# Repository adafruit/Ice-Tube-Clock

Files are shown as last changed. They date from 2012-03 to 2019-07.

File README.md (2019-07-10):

# Ice Tube Clock kit - v1.1

__Format is EagleCAD schematic and board layout__

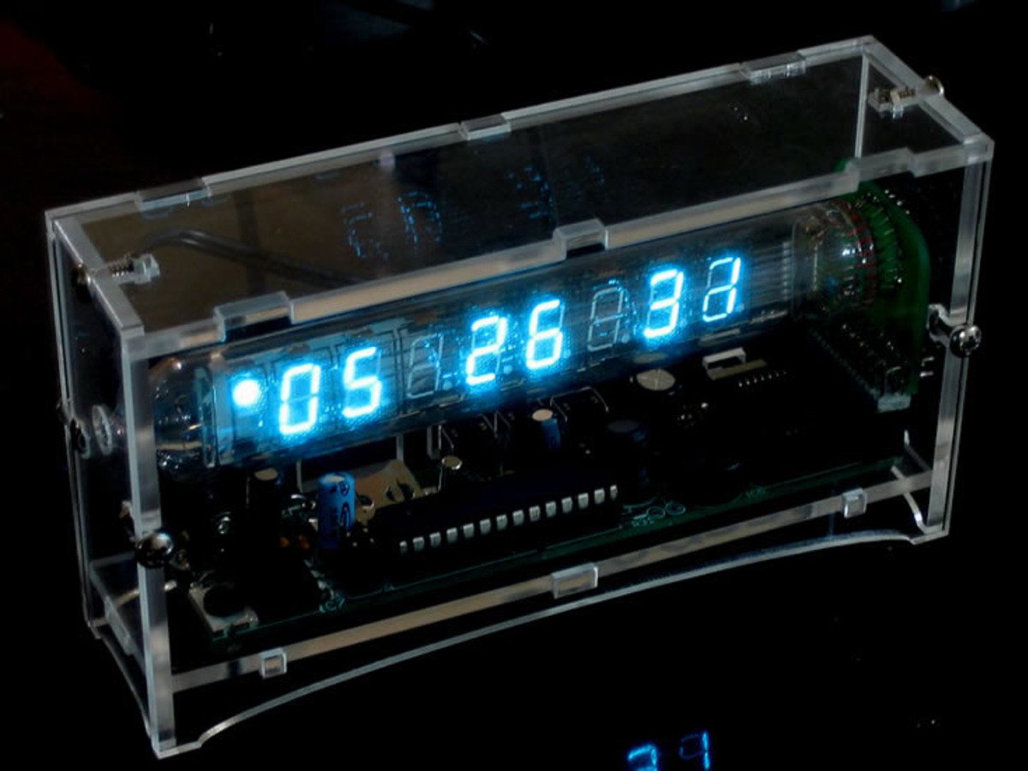
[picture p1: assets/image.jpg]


This is our first clock kit design, made with a retro Russian display tube!

* Cool glowing blue tube with 8 digits, PM dot and alarm on/off indicator
* Adjustable brightness
* Alarm with volume adjust
* Precision watch crystal keeps time with under 20ppm (0.0002%) error (< 2 seconds a day)
* Clear acrylic enclosure protects clock from you and you from clock
* Battery backup will let the clock keep the time for up to 2 weeks without power
* Selectable 12h or 24h display
* Displays day and date on button press
* 10 minute snooze
* Integrated boost converter so it can run off of standard DC wall adapters, works in any country regardless of mains power
* Great for desk or night table use, the clock measures 4.9" x 2.9" x 1.3" (12.5cm x 7.4cm x 3.3cm)
* Completely open source hardware and software, ready to be hacked and modded!

Complete kit comes with [a 110/220V 9VDC power supply](https://www.adafruit.com/products/63) (a $1 plug adapter from your local hardware store will allow it to be used worldwide), all components including PCB, vacuum fluorescent tube, backup battery and a clear acrylic enclosure. Assembly is required! This kit is made of through-hole components but is best built by someone with previous soldering experience as there are many parts and steps.

For assembly instructions, user manual, code, schematics, and more, please visit the [Ice Tube Clock webpage!](https://learn.adafruit.com/ice-tube-clock-kit/)

**Note: This kit is super popular, and the supply of tubes is harder to get. Thus the price is going to increase slowly but surely until the tubes are unavailable & the kit is discontinued. Thanks for your understanding!**

## License

Adafruit invests time and resources providing this open source design, 
please support Adafruit and open-source hardware by purchasing 
products from Adafruit!

Designed by Adafruit Industries.  
Creative Commons Attribution, Share-Alike license, check license.txt for more information
All text above must be included in any redistribution

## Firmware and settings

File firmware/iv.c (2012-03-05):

/***************************************************************************
 Ice Tube Clock with GPS firmware July 22, 2010
 (c) 2010 Limor Fried / Adafruit Industries
 GPS Capability added by Devlin Thyne

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
THE SOFTWARE IS PROVIDED "AS IS", WITHOUT WARRANTY OF ANY KIND, EXPRESS OR
IMPLIED, INCLUDING BUT NOT LIMITED TO THE WARRANTIES OF MERCHANTABILITY,
FITNESS FOR A PARTICULAR PURPOSE AND NONINFRINGEMENT. IN NO EVENT SHALL THE
AUTHORS OR COPYRIGHT HOLDERS BE LIABLE FOR ANY CLAIM, DAMAGES OR OTHER
LIABILITY, WHETHER IN AN ACTION OF CONTRACT, TORT OR OTHERWISE, ARISING FROM,
OUT OF OR IN CONNECTION WITH THE SOFTWARE OR THE USE OR OTHER DEALINGS IN
THE SOFTWARE.
****************************************************************************/

#include <avr/io.h>      
#include <string.h>
#include <avr/interrupt.h>   // Interrupts and timers
#include <util/delay.h>      // Blocking delay functions
#include <avr/pgmspace.h>    // So we can store the 'font table' in ROM
#include <avr/eeprom.h>      // Date/time/pref backup in permanent EEPROM
#include <avr/wdt.h>     // Watchdog timer to repair lockups
#include <stdlib.h>

#include "iv.h"
#include "util.h"
#include "fonttable.h"

uint8_t region = REGION_US;

// These variables store the current time.
volatile int8_t time_s, time_m, time_h;
// ... and current date
volatile int8_t date_m, date_d, date_y;

// how loud is the speaker supposed to be?
volatile uint8_t volume;

// whether the alarm is on, going off, and alarm time
volatile uint8_t alarm_on, alarming, alarm_h, alarm_m;

// what is being displayed on the screen? (eg time, date, menu...)
volatile uint8_t displaymode;

// are we in low power sleep mode?
volatile uint8_t sleepmode = 0;

volatile uint8_t timeunknown = 0;        // MEME
volatile uint8_t restored = 0;

// String buffer for processing GPS data:
char strBuffer[BUFFERSIZE];
uint8_t intBufferStatus = 0;

// Variables for the timezone offset if using GPS.
int8_t intTimeZoneHour = -6;  //Because Colorado is my time zone...
uint8_t intTimeZoneMin = 0;


// Our display buffer, which is updated to show the time/date/etc
// and is multiplexed onto the tube
uint8_t display[DISPLAYSIZE]; // stores segments, not values!
uint8_t currdigit = 0;        // which digit we are currently multiplexing

// This table allow us to index between what digit we want to light up
// and what the pin number is on the MAX6921 see the .h for values.
// Stored in ROM (PROGMEM) to save RAM
const uint8_t digittable[] PROGMEM = {
  DIG_9, DIG_8, DIG_7, DIG_6, DIG_5, DIG_4, DIG_3, DIG_2, DIG_1
};
PGM_P digittable_p PROGMEM = digittable;

// This table allow us to index between what segment we want to light up
// and what the pin number is on the MAX6921 see the .h for values.
// Stored in ROM (PROGMEM) to save RAM
const uint8_t segmenttable[] PROGMEM = {
  SEG_H, SEG_G,  SEG_F,  SEG_E,  SEG_D,  SEG_C,  SEG_B,  SEG_A 
};
PGM_P segmenttable_p PROGMEM = segmenttable;

// muxdiv and MUX_DIVIDER divides down a high speed interrupt (31.25KHz)
// down so that we can refresh at about 100Hz (31.25KHz / 300)
// We refresh the entire display at 100Hz so each digit is updated
// 100Hz/DISPLAYSIZE
uint16_t muxdiv = 0;
#define MUX_DIVIDER (300 / DISPLAYSIZE)

// Likewise divides 100Hz down to 1Hz for the alarm beeping
uint16_t alarmdiv = 0;
#define ALARM_DIVIDER 100

// How long we have been snoozing
uint16_t snoozetimer = 0;

// We have a non-blocking delay function, milliseconds is updated by
// an interrupt
volatile uint16_t milliseconds = 0;
void delayms(uint16_t ms) {
  sei();

  milliseconds = 0;
  while (milliseconds < ms);
}

// When the alarm is going off, pressing a button turns on snooze mode
// this sets the snoozetimer off in MAXSNOOZE seconds - which turns on
// the alarm again
void setsnooze(void) {
  //snoozetimer = eeprom_read_byte((uint8_t *)EE_SNOOZE);
  //snoozetimer *= 60; // convert minutes to seconds
  snoozetimer = MAXSNOOZE;
  DEBUGP("snooze");
  display_str("snoozing");
  displaymode = SHOW_SNOOZE;
  delayms(1000);
  displaymode = SHOW_TIME;
}

// we reset the watchdog timer 
void kickthedog(void) {
  
  wdt_reset();

}

// called @ (F_CPU/256) = ~30khz (31.25 khz)
SIGNAL (SIG_OVERFLOW0) {
  // allow other interrupts to go off while we're doing display updates
  sei();

  // kick the dog
  kickthedog();

  // divide down to 100Hz * digits
  muxdiv++;
  if (muxdiv < MUX_DIVIDER)
    return;
  muxdiv = 0;
  // now at 100Hz * digits

  // ok its not really 1ms but its like within 10% :)
  milliseconds++;

  // Cycle through each digit in the display
  if (currdigit >= DISPLAYSIZE)
    currdigit = 0;

  // Set the current display's segments
  setdisplay(currdigit, display[currdigit]);
  // and go to the next
  currdigit++;

  // check if we should have the alarm on
  if (alarming && !snoozetimer) {
    alarmdiv++;
    if (alarmdiv > ALARM_DIVIDER) {
      alarmdiv = 0;
    } else {
      return;
    }
    // This part only gets reached at 1Hz

    // This sets the buzzer frequency
    ICR1 = 250;
    OCR1A = OCR1B = ICR1/2;

    // ok alarm is ringing!
    if (alarming & 0xF0) { // top bit indicates pulsing alarm state
      alarming &= ~0xF0;
      TCCR1B &= ~_BV(CS11); // turn buzzer off!
    } else {
      alarming |= 0xF0;
      TCCR1B |= _BV(CS11); // turn buzzer on!
    }
  }
  
}


// We use the pin change interrupts to detect when buttons are pressed

// These store the current button states for all 3 buttons. We can 
// then query whether the buttons are pressed and released or pressed
// This allows for 'high speed incrementing' when setting the time
volatile uint8_t last_buttonstate = 0, just_pressed = 0, pressed = 0;
volatile uint8_t buttonholdcounter = 0;

// This interrupt detects switches 1 and 3
SIGNAL(SIG_PIN_CHANGE2) {
  PCICR = 0;
  // allow interrupts while we're doing this
  sei();

  if (! (PIND & _BV(BUTTON1))) {
    // button1 is pressed
    if (! (last_buttonstate & 0x1)) { // was not pressed before
      delayms(10);                    // debounce
      if (PIND & _BV(BUTTON1)) {      // filter out bounce
	PCICR = _BV(PCIE0) | _BV(PCIE2);
	return;
      }
      tick();                         // make a noise
      // check if we will snag this button press for snoozing
      if (alarming) {
	// turn on snooze
	setsnooze();
	PCICR = _BV(PCIE0) | _BV(PCIE2);
	return;
      }
      last_buttonstate |= 0x1;
      just_pressed |= 0x1;
      DEBUGP("b1");
    }
  } else {
    last_buttonstate &= ~0x1;
  }

  if (! (PIND & _BV(BUTTON3))) {
    // button3 is pressed
    if (! (last_buttonstate & 0x4)) { // was not pressed before
      delayms(10);                    // debounce
      if (PIND & _BV(BUTTON3)) {      // filter out bounces
	PCICR = _BV(PCIE0) | _BV(PCIE2);
	return;
      }
      buttonholdcounter = 2;          // see if we're press-and-holding
      while (buttonholdcounter) {
	if (PIND & _BV(BUTTON3)) {        // released
	  tick();                         // make a noise
	  last_buttonstate &= ~0x4;
	  // check if we will snag this button press for snoozing
	  if (alarming) {
	    // turn on snooze
	    setsnooze();
	    PCICR = _BV(PCIE0) | _BV(PCIE2);
	    return;
	  }
	  DEBUGP("b3");
	  just_pressed |= 0x4;
	  PCICR = _BV(PCIE0) | _BV(PCIE2);
	  return;
	}
      }
      last_buttonstate |= 0x4;
      pressed |= 0x4;                 // held down
    }
  } else {
    pressed = 0;                      // button released
    last_buttonstate &= ~0x4;
  }
  PCICR = _BV(PCIE0) | _BV(PCIE2);
}

// Just button #2
SIGNAL(SIG_PIN_CHANGE0) {
  PCICR = 0;
  sei();
  if (! (PINB & _BV(BUTTON2))) {
    // button2 is pressed
    if (! (last_buttonstate & 0x2)) { // was not pressed before
      delayms(10);                    // debounce
      if (PINB & _BV(BUTTON2)) {      // filter out bounces
	PCICR = _BV(PCIE0) | _BV(PCIE2);
	return;
      }
      tick();                         // make a noise
      // check if we will snag this button press for snoozing
      if (alarming) {
	setsnooze(); 	// turn on snooze
	PCICR = _BV(PCIE0) | _BV(PCIE2);
	return;
      }
      last_buttonstate |= 0x2;
      just_pressed |= 0x2;
      DEBUGP("b2");
    }
  } else {
    last_buttonstate &= ~0x2;
  }
  PCICR = _BV(PCIE0) | _BV(PCIE2);
}

// This variable keeps track of whether we have not pressed any
// buttons in a few seconds, and turns off the menu display
volatile uint8_t timeoutcounter = 0;

// this goes off once a second
SIGNAL (TIMER2_OVF_vect) {
  CLKPR = _BV(CLKPCE);  //MEME
  CLKPR = 0;

  time_s++;             // one second has gone by

  fix_time();

  // If we're in low power mode we should get out now since the display is off
  if (sleepmode)
    return;
   

  if (displaymode == SHOW_TIME) {
    if (timeunknown && (time_s % 2)) {
      display_str("        ");
    } else {
      display_time(time_h, time_m, time_s);
    }
    if (alarm_on)
      display[0] |= 0x2;
    else 
      display[0] &= ~0x2;
    
  }

  check_alarm(time_h, time_m, time_s);

  if (timeoutcounter)
    timeoutcounter--;
  if (buttonholdcounter)
    buttonholdcounter--;
  if (snoozetimer) {
    snoozetimer--;
    if (snoozetimer % 2) 
      display[0] |= 0x2;
    else
      display[0] &= ~0x2;
  }
}

SIGNAL(SIG_INTERRUPT0) {
  uart_putchar('i');
  uint8_t x = ALARM_PIN & _BV(ALARM);
  sei();
  delayms(10); // wait for debouncing
  if (x != (ALARM_PIN & _BV(ALARM)))
    return;
  setalarmstate();
}



SIGNAL(SIG_COMPARATOR) {
  //DEBUGP("COMP");
  if (ACSR & _BV(ACO)) {
    //DEBUGP("HIGH");
    if (!sleepmode) {
      VFDSWITCH_PORT |= _BV(VFDSWITCH); // turn off display
      VFDCLK_PORT &= ~_BV(VFDCLK) & ~_BV(VFDDATA); // no power to vfdchip
      BOOST_PORT &= ~_BV(BOOST); // pull boost fet low
      SPCR  &= ~_BV(SPE); // turn off spi
      if (restored) {
	eeprom_write_byte((uint8_t *)EE_MIN, time_m);
	eeprom_write_byte((uint8_t *)EE_SEC, time_s);
      }
      DEBUGP("z");
      TCCR0B = 0; // no boost
      volume = 0; // low power buzzer
      PCICR = 0;  // ignore buttons

      app_start();
    }
  } else {
    //DEBUGP("LOW");
    if (sleepmode) {
      if (restored) {
	eeprom_write_byte((uint8_t *)EE_MIN, time_m);
	eeprom_write_byte((uint8_t *)EE_SEC, time_s);
      }
      DEBUGP("WAKERESET"); 
      app_start();
    }
  }
}


/*********************** Main app **********/

uint32_t t;

void gotosleep(void) {
  // battery
  //if (sleepmode) //already asleep?
  //  return;
  //DEBUGP("sleeptime");
  
  sleepmode = 1;
  VFDSWITCH_PORT |= _BV(VFDSWITCH); // turn off display
  SPCR  &= ~_BV(SPE); // turn off spi
  VFDCLK_PORT &= ~_BV(VFDCLK) & ~_BV(VFDDATA); // no power to vfdchip
  BOOST_PORT &= ~_BV(BOOST); // pull boost fet low
  TCCR0B = 0; // no boost
  volume = 0; // low power buzzer
  PCICR = 0;  // ignore buttons

  // sleep time!
  //beep(3520, 1);
  //beep(1760, 1);
  //beep(880, 1);
  // turn beeper off
  PORTB &= ~_BV(SPK1) & ~_BV(SPK2); 
  
  // turn off pullups
  PORTD &= ~_BV(BUTTON1) & ~_BV(BUTTON3);
  PORTB &= ~_BV(BUTTON2);
  DDRD &= ~_BV(BUTTON1) & ~_BV(BUTTON3);
  DDRB &= ~_BV(BUTTON2);
  ALARM_PORT &= ~_BV(ALARM);
  ALARM_DDR &= ~_BV(ALARM);
  

  // reduce the clock speed
  CLKPR = _BV(CLKPCE);
  CLKPR = _BV(CLKPS3);
  
  //  PPR |= _BV(PRUSART0) | _BV(PRADC) | _BV(PRSPI) | _BV(PRTIM1) | _BV(PRTIM0) | _BV(PRTWI);
  PORTC |= _BV(4);  // sleep signal
  SMCR |= _BV(SM1) | _BV(SM0) | _BV(SE); // sleep mode
  asm("sleep"); 
  CLKPR = _BV(CLKPCE);
  CLKPR = 0;
  PORTC &= ~_BV(4);
}
 
 void wakeup(void) {
   if (!sleepmode)
     return;
   CLKPR = _BV(CLKPCE);
   CLKPR = 0;
   DEBUGP("waketime");
   sleepmode = 0;
   // plugged in
   // wait to verify
   _delay_ms(20);
   if (ACSR & _BV(ACO)) 
     return;
   
   // turn on pullups
   initbuttons();

   // turn on boost
   boost_init(eeprom_read_byte((uint8_t *)EE_BRIGHT));

   // turn on vfd control
   vfd_init();

   // turn on display
   VFDSWITCH_PORT &= ~_BV(VFDSWITCH); 
   VFDBLANK_PORT &= ~_BV(VFDBLANK);
   volume = eeprom_read_byte((uint8_t *)EE_VOLUME); // reset
   
   speaker_init();

   kickthedog();

   setalarmstate();

   // wake up sound
   beep(880, 1);
   beep(1760, 1);
   beep(3520, 1);

   kickthedog();
 }


void initbuttons(void) {
    DDRB =  _BV(VFDCLK) | _BV(VFDDATA) | _BV(SPK1) | _BV(SPK2);
    DDRD = _BV(BOOST) | _BV(VFDSWITCH);
    DDRC = _BV(VFDLOAD) | _BV(VFDBLANK) | _BV(4);
    PORTD = _BV(BUTTON1) | _BV(BUTTON3) | _BV(ALARM);
    PORTB = _BV(BUTTON2);

    PCICR = _BV(PCIE0) | _BV(PCIE2);
    PCMSK0 = _BV(PCINT0);
    PCMSK2 = _BV(PCINT21) | _BV(PCINT20);    
}



int main(void) {
  //  uint8_t i;
  uint8_t mcustate;

  // turn boost off
  TCCR0B = 0;
  BOOST_DDR |= _BV(BOOST);
  BOOST_PORT &= ~_BV(BOOST); // pull boost fet low

  // check if we were reset
  mcustate = MCUSR;
  MCUSR = 0;

  uart_putw_hex(mcustate);

  wdt_disable();
  // now turn it back on... 2 second time out
  //WDTCSR |= _BV(WDP0) | _BV(WDP1) | _BV(WDP2);
  //WDTCSR = _BV(WDE);
  wdt_enable(WDTO_2S);
  kickthedog();

  // we lost power at some point so lets alert the user
  // that the time may be wrong (the clock still works)
  timeunknown = 1;

  // have we read the time & date from eeprom?
  restored = 0;

  // setup uart
  uart_init(BRRL_4800);

  //DEBUGP("VFD Clock");
  DEBUGP("!");
  uart_puts("\n\rHello World!\n\r");
  uart_puts("\n\rBuffer size is:\t");
  uart_putw_dec(BUFFERSIZE);
  uart_puts("\n\r");

  //DEBUGP("turning on anacomp");
  // set up analog comparator
  ACSR = _BV(ACBG) | _BV(ACIE); // use bandgap, intr. on toggle!
  _delay_ms(1);
  // settle!
  if (ACSR & _BV(ACO)) {
    // hmm we should not interrupt here
    ACSR |= _BV(ACI);

    // even in low power mode, we run the clock 
    DEBUGP("clock init");
    clock_init();  

  } else {
    // we aren't in low power mode so init stuff

    // init IOs
    initbuttons();
    
    VFDSWITCH_PORT &= ~_BV(VFDSWITCH);
    
    DEBUGP("turning on buttons");
    // set up button interrupts
    DEBUGP("turning on alarmsw");
    // set off an interrupt if alarm is set or unset
    EICRA = _BV(ISC00);
    EIMSK = _BV(INT0);
  
    displaymode = SHOW_TIME;
    DEBUGP("vfd init");
    vfd_init();
    
    DEBUGP("boost init");
    boost_init(eeprom_read_byte((uint8_t *)EE_BRIGHT));
    sei();

    //Load and check the timezone information
    intTimeZoneHour = eeprom_read_byte((uint8_t *)EE_ZONE_HOUR);
    if ( ( 12 < intTimeZoneHour ) || ( -12 > intTimeZoneHour ) )
      intTimeZoneHour = 0;

    intTimeZoneMin = eeprom_read_byte((uint8_t *)EE_ZONE_MIN);
    if ( ( 60 < intTimeZoneMin ) || ( 0 > intTimeZoneMin ) )
      intTimeZoneMin = 0;

    region = eeprom_read_byte((uint8_t *)EE_REGION);
    
    DEBUGP("speaker init");
    speaker_init();

    beep(4000, 1);

    DEBUGP("clock init");
    clock_init();  

    DEBUGP("alarm init");
    setalarmstate();
  }
  DEBUGP("done");
  while (1) {
    //_delay_ms(100);
    kickthedog();
    //uart_putc_hex(ACSR);
    if (ACSR & _BV(ACO)) {
      // DEBUGP("SLEEPYTIME");
      gotosleep();
      continue;
    }
    //DEBUGP(".");
    if (just_pressed & 0x1) {
      just_pressed = 0;
      switch(displaymode) {
      case (SHOW_TIME):
	displaymode = SET_ALARM;
	display_str("set alarm");
	set_alarm();
	break;
      case (SET_ALARM):
	displaymode = SET_TIME;
	display_str("set time");
	set_time();
	timeunknown = 0;
	break;
      case (SET_TIME):
	displaymode = SET_DATE;
	display_str("set date");
	set_date();
	break;
      case (SET_DATE):
	//displaymode = SET_BRIGHTNESS;
	//display_str("set brit");
	//set_brightness();
        displaymode = SET_ZONE;
        display_str("set zone");
        set_timezone();
	break;
      case (SET_ZONE):
        displaymode = SET_BRIGHTNESS;
        display_str("set brit");
        set_brightness();
        break;
      case (SET_BRIGHTNESS):
	displaymode = SET_VOLUME;
	display_str("set vol ");
	set_volume();
	break;
      case (SET_VOLUME):
	displaymode = SET_REGION;
	display_str("set regn");
	set_region();
	break;
	/*
      case (SET_REGION):
	displaymode = SET_SNOOZE;
	display_str("set snoz");
	set_snooze();
	break;
	*/
      default:
	displaymode = SHOW_TIME;
      }
    } else if ((just_pressed & 0x2) || (just_pressed & 0x4)) {
      just_pressed = 0;
      displaymode = NONE;
      display_date(DAY);

      kickthedog();
      delayms(1500);
      kickthedog();

      displaymode = SHOW_TIME;     
    }

    //Check to see if GPS data is ready:
    if ( gpsdataready() ) {
       getgpstime();

    }
 
  }
}

/**************************** SUB-MENUS *****************************/

void set_alarm(void) 
{
  uint8_t mode;
  uint8_t hour, min, sec;
    
  hour = min = sec = 0;
  mode = SHOW_MENU;

  hour = alarm_h;
  min = alarm_m;
  sec = 0;
  
  timeoutcounter = INACTIVITYTIMEOUT;
  
  while (1) {
    if (just_pressed & 0x1) { // mode change
      return;
    }
    if (just_pressed || pressed) {
      timeoutcounter = INACTIVITYTIMEOUT;  
      // timeout w/no buttons pressed after 3 seconds?
    } else if (!timeoutcounter) {
      //timed out!
      displaymode = SHOW_TIME;     
      alarm_h = hour;
      alarm_m = min;
      eeprom_write_byte((uint8_t *)EE_ALARM_HOUR, alarm_h);    
      eeprom_write_byte((uint8_t *)EE_ALARM_MIN, alarm_m);    
      return;
    }
    if (just_pressed & 0x2) {
      just_pressed = 0;
      if (mode == SHOW_MENU) {
	// ok now its selected
	mode = SET_HOUR;
	display_alarm(hour, min);
	display[1] |= 0x1;
	display[2] |= 0x1;	
      } else if (mode == SET_HOUR) {
	mode = SET_MIN;
	display_alarm(hour, min);
	display[4] |= 0x1;
	display[5] |= 0x1;
      } else {
	// done!
	alarm_h = hour;
	alarm_m = min;
	eeprom_write_byte((uint8_t *)EE_ALARM_HOUR, alarm_h);    
	eeprom_write_byte((uint8_t *)EE_ALARM_MIN, alarm_m);    
	displaymode = SHOW_TIME;
	return;
      }
    }
    if ((just_pressed & 0x4) || (pressed & 0x4)) {
      just_pressed = 0;

      if (mode == SET_HOUR) {
	hour = (hour+1) % 24;
	display_alarm(hour, min);
	display[1] |= 0x1;
	display[2] |= 0x1;
      }
      if (mode == SET_MIN) {
	min = (min+1) % 60;
	display_alarm(hour, min);
	display[4] |= 0x1;
	display[5] |= 0x1;
      }

      if (pressed & 0x4)
	delayms(75);
    }
  }
}

void set_time(void) 
{
  uint8_t mode;
  uint8_t hour, min, sec;
    
  hour = time_h;
  min = time_m;
  sec = time_s;
  mode = SHOW_MENU;

  timeoutcounter = INACTIVITYTIMEOUT;
  
  while (1) {
    if (just_pressed & 0x1) { // mode change
      return;
    }
    if (just_pressed || pressed) {
      timeoutcounter = INACTIVITYTIMEOUT;  
      // timeout w/no buttons pressed after 3 seconds?
    } else if (!timeoutcounter) {
      //timed out!
      displaymode = SHOW_TIME;     
      return;
    }
    if (just_pressed & 0x2) {
      just_pressed = 0;
      if (mode == SHOW_MENU) {
	hour = time_h;
	min = time_m;
	sec = time_s;

	// ok now its selected
	mode = SET_HOUR;
	display_time(hour, min, sec);
	display[1] |= 0x1;
	display[2] |= 0x1;	
      } else if (mode == SET_HOUR) {
	mode = SET_MIN;
	display_time(hour, min, sec);
	display[4] |= 0x1;
	display[5] |= 0x1;
      } else if (mode == SET_MIN) {
	mode = SET_SEC;
	display_time(hour, min, sec);
	display[7] |= 0x1;
	display[8] |= 0x1;
      } else {
	// done!
	time_h = hour;
	time_m = min;
	time_s = sec;
	displaymode = SHOW_TIME;
	return;
      }
    }
    if ((just_pressed & 0x4) || (pressed & 0x4)) {
      just_pressed = 0;
      
      if (mode == SET_HOUR) {
	hour = (hour+1) % 24;
	display_time(hour, min, sec);
	display[1] |= 0x1;
	display[2] |= 0x1;
	time_h = hour;
	eeprom_write_byte((uint8_t *)EE_HOUR, time_h);    
      }
      if (mode == SET_MIN) {
	min = (min+1) % 60;
	display_time(hour, min, sec);
	display[4] |= 0x1;
	display[5] |= 0x1;
	eeprom_write_byte((uint8_t *)EE_MIN, time_m);
	time_m = min;
      }
      if ((mode == SET_SEC) ) {
	sec = (sec+1) % 60;
	display_time(hour, min, sec);
	display[7] |= 0x1;
	display[8] |= 0x1;
	time_s = sec;
      }
      
      if (pressed & 0x4)
	delayms(75);
    }
  }
}
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

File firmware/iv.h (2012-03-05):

/***************************************************************************
 Ice Tube Clock with GPS firmware July 22, 2010
 (c) 2010 Limor Fried / Adafruit Industries
 GPS Capability added by Devlin Thyne

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
THE SOFTWARE IS PROVIDED "AS IS", WITHOUT WARRANTY OF ANY KIND, EXPRESS OR
IMPLIED, INCLUDING BUT NOT LIMITED TO THE WARRANTIES OF MERCHANTABILITY,
FITNESS FOR A PARTICULAR PURPOSE AND NONINFRINGEMENT. IN NO EVENT SHALL THE
AUTHORS OR COPYRIGHT HOLDERS BE LIABLE FOR ANY CLAIM, DAMAGES OR OTHER
LIABILITY, WHETHER IN AN ACTION OF CONTRACT, TORT OR OTHERWISE, ARISING FROM,
OUT OF OR IN CONNECTION WITH THE SOFTWARE OR THE USE OR OTHER DEALINGS IN
THE SOFTWARE.
****************************************************************************/


#define halt(x)  while (1)

#define DEBUG 1
#define DEBUGP(x)  if (DEBUG) {putstring_nl(x);}

//The year the clock was programmed, used for error checking
#define PROGRAMMING_YEAR 10

#define REGION_US 0
#define REGION_EU 1

// date format
#define DATE 0  // mm-dd-yy
#define DAY 1   // thur jan 1

// String buffer size:
#define BUFFERSIZE 128

#define DISPLAYSIZE 9

#define MAXSNOOZE 600 // 10 minutes
#define INACTIVITYTIMEOUT 10 // how many seconds we will wait before turning off menus


#define BEEP_8KHZ 5
#define BEEP_4KHZ 10
#define BEEP_2KHZ 20
#define BEEP_1KHZ 40

#define EE_YEAR 1
#define EE_MONTH 2
#define EE_DAY 3
#define EE_HOUR 4
#define EE_MIN 5
#define EE_SEC 6
#define EE_ALARM_HOUR 7 
#define EE_ALARM_MIN 8
#define EE_BRIGHT 9
#define EE_VOLUME 10
#define EE_REGION 11
#define EE_SNOOZE 12
#define EE_ZONE_HOUR 13
#define EE_ZONE_MIN 14

void delay(uint16_t delay);

void (*app_start)(void) = 0x0000;

void clock_init(void);
void initbuttons(void);
void boost_init(uint8_t pwm);
void vfd_init(void);
void speaker_init(void);

void display_time(uint8_t h, uint8_t m, uint8_t s);
void display_date(uint8_t style);
void display_str(char *s);
void display_alarm(uint8_t h, uint8_t m);
void display_timezone(int8_t h, uint8_t m);

void set_time(void);
void set_alarm(void);
void set_date(void);
void set_brightness(void);
void set_volume(void);
void set_region(void);
void set_snooze(void); // not activated by default

//Checks the alarm against the passed time.
void check_alarm(uint8_t h, uint8_t m, uint8_t s);

//Fixes the time variables whenever time is changed
void fix_time(void);

//Set the time zone:
void set_timezone(void);

void beep(uint16_t freq, uint8_t times);
void tick(void);

uint8_t leapyear(uint16_t y);
void setalarmstate(void);

void setdisplay(uint8_t digit, uint8_t segments);
void vfd_send(uint32_t d);
void spi_xfer(uint8_t c);

//GPS serial data handling functions:
uint8_t gpsdataready(void);
void getgpstime(void);
void setgpstime(char* str);
void setgpsdate(char* str);


// displaymode
#define NONE 99
#define SHOW_TIME 0
#define SHOW_DATE 1
#define SHOW_ALARM 2
#define SET_TIME 3
#define SET_ALARM 4
#define SET_DATE 5
#define SET_BRIGHTNESS 6
#define SET_VOLUME 7
#define SET_REGION 8
#define SHOW_SNOOZE 9
#define SET_SNOOZE 10
#define SET_ZONE 11

// sub-mode settings
#define SHOW_MENU 0
// alarm/time/zone
#define SET_HOUR 1
#define SET_MIN 2
#define SET_SEC 3
// date
#define SET_MONTH 1
#define SET_DAY 2
#define SET_YEAR 3
//brightness
#define SET_BRITE 1
//volume
#define SET_VOL 1
//region
#define SET_REG 1


#define BOOST PD6
#define BOOST_DDR DDRD
#define BOOST_PORT PORTD

#define BUTTON1 PD5
#define BUTTON2 PB0
#define BUTTON3 PD4

#define VFDSWITCH PD3
#define VFDSWITCH_DDR DDRD
#define VFDSWITCH_PORT PORTD
#define VFDCLK PB5
#define VFDCLK_DDR DDRB
#define VFDCLK_PORT PORTB
#define VFDDATA PB3
#define VFDDATA_DDR DDRB
#define VFDDATA_PORT PORTB
#define VFDLOAD PC0
#define VFDLOAD_DDR DDRC
#define VFDLOAD_PORT PORTC
#define VFDBLANK PC3
#define VFDBLANK_DDR DDRC
#define VFDBLANK_PORT PORTC

#define ALARM PD2
#define ALARM_DDR DDRD
#define ALARM_PORT PORTD
#define ALARM_PIN PIND

#define SPK1 PB1
#define SPK2 PB2
#define SPK_PORT PORTB
#define SPK_DDR DDRB

#define SEG_A 19
#define SEG_B 17
#define SEG_C 14
#define SEG_D 13
#define SEG_E 15
#define SEG_F 18
#define SEG_G 16
#define SEG_H 11

#define DIG_1 4
#define DIG_2 12
#define DIG_3 5
#define DIG_4 10
#define DIG_5 6
#define DIG_6 9
#define DIG_7 8
#define DIG_8 7
#define DIG_9 3

#define nop asm("nop")

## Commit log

2010-07-15 Adding CAD files
    [InductCoilSMPS.ods, icetube.brd, icetube.sch]
2010-10-26 Updated with pmosfet
    [icetube.brd, icetube.sch]
2012-03-05 Case in SVG
